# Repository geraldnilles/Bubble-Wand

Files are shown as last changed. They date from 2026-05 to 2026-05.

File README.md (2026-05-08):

# Bubble Wand

A custom-designed, 3D-printable bubble wand and storage rack, built with [OpenSCAD](https://openscad.org/) and the [BOSL2](https://github.com/BelfrySCAD/BOSL2) library.

Designed for my daughters and their friends.

---

## Wand

OpenSCAD Source: [Bubble_Wand.scad](./Bubble_Wand.scad)

The wand consists of two printed parts:

| Part | Description |
|---|---|
| **Ring** | A thick, toothed bubble loop that holds the bubble film. The serrated edges help retain more bubble solution for bigger, stronger bubbles. |
| **Handle** | A long, slim rod that fits small hands comfortably. |

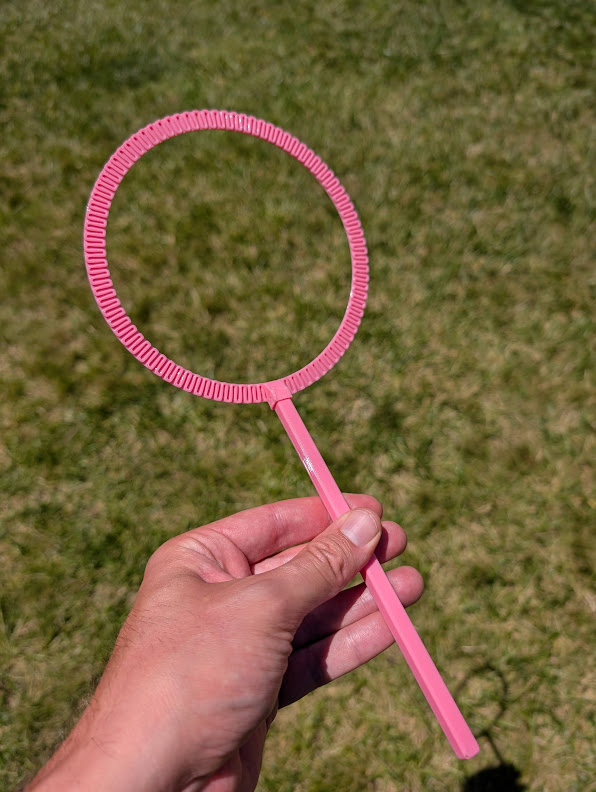
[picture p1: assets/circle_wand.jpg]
Printed bubble wand being held


Both parts are printed separately and glued together with superglue (CA glue). The handle adapter on the ring creates a strong mechanical bond.

### Ring Shapes

The wand supports **two ring profiles**, controlled by commenting/uncommenting the `radius()` function in `Bubble_Wand.scad`:

| Shape | Code |
|---|---|
| **Circular (default)** | `function radius(r,angle) = r;` |
| **Oval** | `function radius(r,angle) = ((0.5*sin(angle))^2+0.75)*r;` |

Simply uncomment your preferred line and comment the other, then re-render.

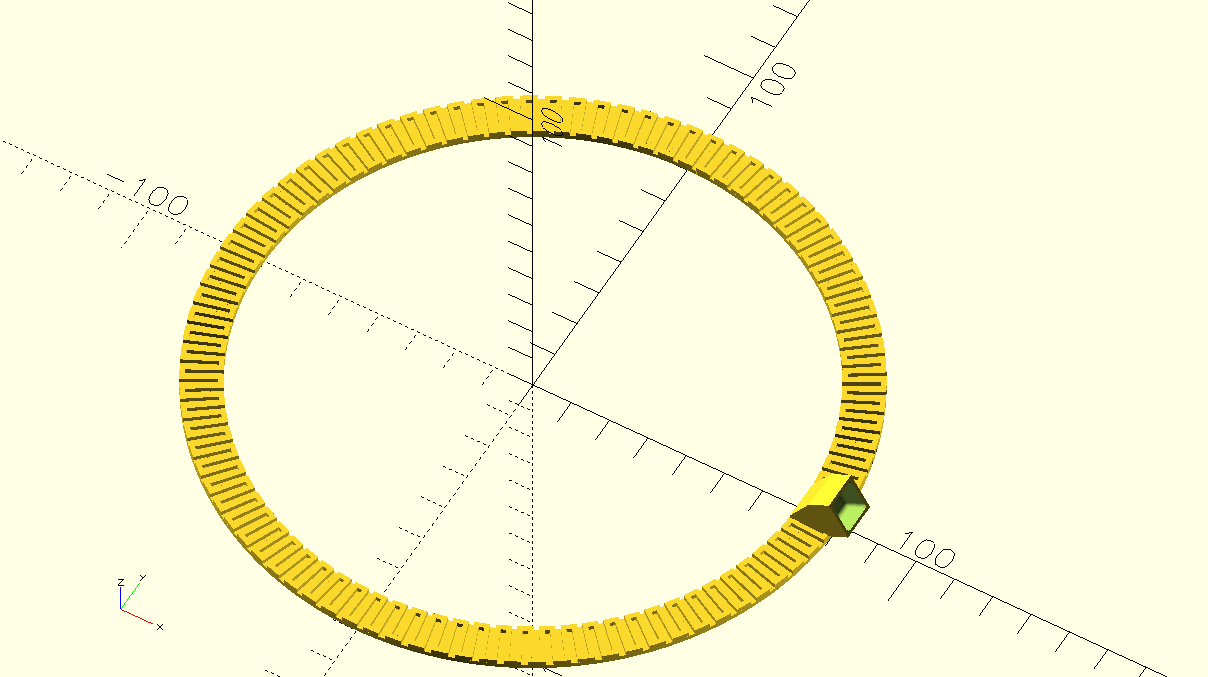
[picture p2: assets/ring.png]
Circular ring render
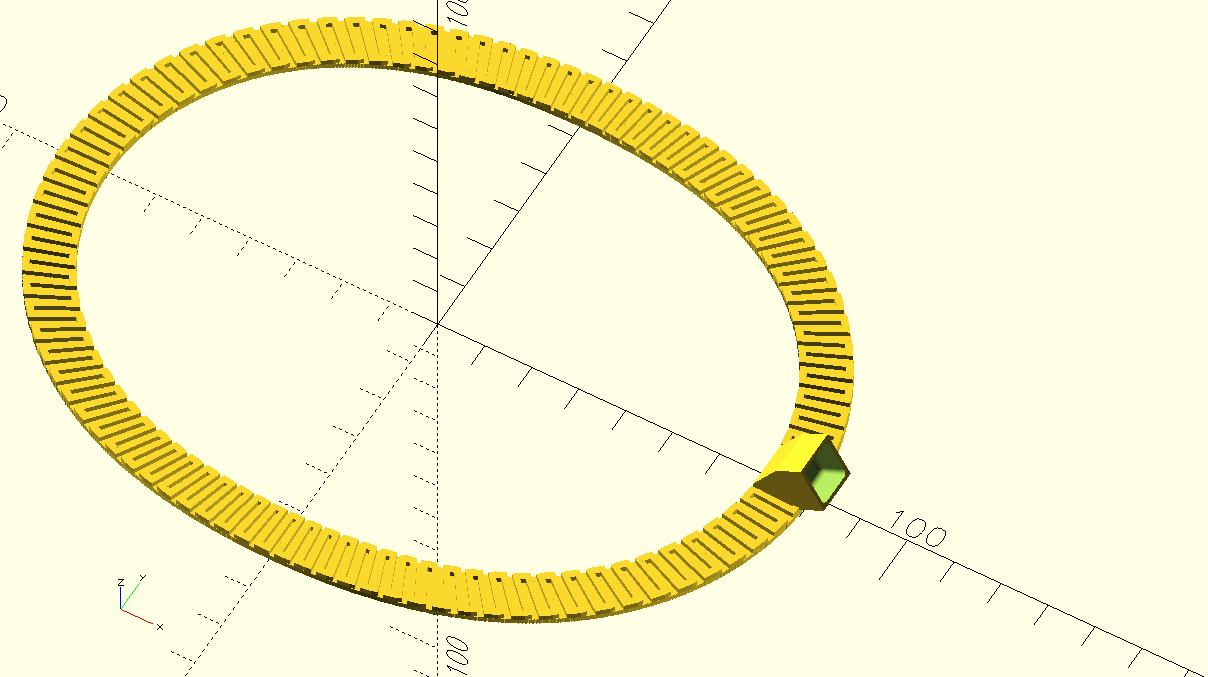
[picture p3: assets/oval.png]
Oval ring render
     

### Optimized for Clean FDM Printing

This model was designed with FDM printing in mind from the start. Every feature serves to minimize retractions, eliminate unnecessary travel moves, and produce a clean, reliable print.

- **Minimal retractions** — The zig-zag tooth pattern is laid down in a continuous, unbroken tool path. The nozzle never needs to lift or cross an open gap, so there's no oozing, stringing, or scarring on the finished part.
- **No travel moves** — Each layer of the ring consists of a single, uninterrupted extrusion. The print head moves from tooth to tooth without retracting or traveling, which saves time and reduces surface blemishes.
- **Optimized for 0.6mm nozzles** — The 1.2mm slot width is exactly two extrusion widths wide on a 0.6mm nozzle. This means the slicer can fill each tooth cleanly without gaps or thin-wall issues.
- **0.4mm nozzle compatibility** — For 0.4mm nozzles, simply increase the extrusion width to 0.6mm in your slicer settings, or decrease the `slot_width` parameter to 0.8mm.

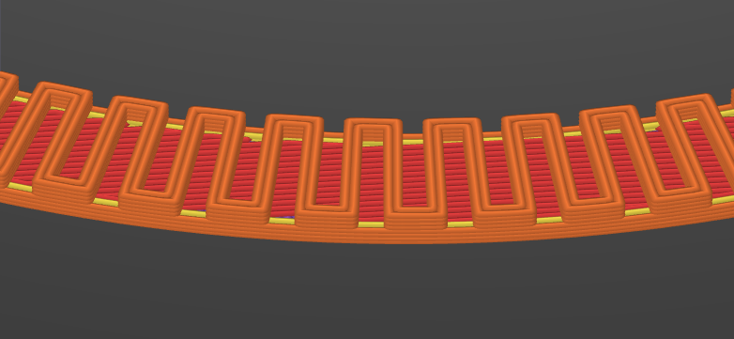
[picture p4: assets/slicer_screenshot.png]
Slicer preview showing the continuous, uninterrupted tool path across the zig-zag tooth pattern


The screenshot above shows the print path as planned by the slicer. Notice how the extruded lines flow continuously across the teeth — there are no retraction dots, no travel lines, and no visible starts or stops on the outer surface.

### Printing Instructions

**Step 1 — Render the ring with its handle adapter:**
```openscad
ring();
handle_adapter();
// handle(x=8);          // <-- keep commented
```

**Step 2 — Render the handle separately:**
```openscad
// ring();
// handle_adapter();
handle(x=8);
```

**Step 3 — Glue.** Apply superglue to the handle adapter (the small rectangular nub on the ring) and insert it into the matching hole on the handle. Hold for 30 seconds.

### Parameters

All adjustable values are at the top of `Bubble_Wand.scad`:

| Variable | Default | Description |
|---|---|---|
| `ring_radius` | `70` | Radius of the bubble ring |
| `ring_thickness` | `10` | Thickness (depth) of the ring's teeth |
| `slot_width` | `1.2` | Width of each tooth/gap |
| `slot_height` | `1.2` | Height of the tooth profile |

---

## Wand Rack / Mount

The [Wand_rack_mount.scad](./Wand_rack_mount.scad) file generates a clamp-on bracket that mounts to the edge of a surface (e.g., a bubble table, plastic stool, or bench). It can securely mount several wands.

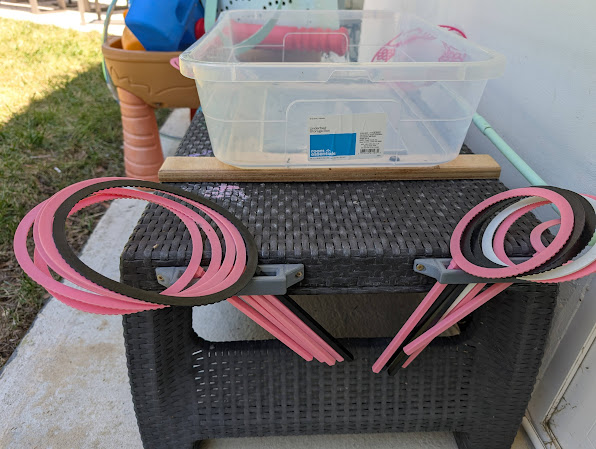
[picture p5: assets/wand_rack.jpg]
Wand rack in use


---

## Bubble Solution

See the [Bubble Solution Recipe](./Bubble_Solution.md) for the homemade bubble mix that makes these wands really shine.

---

## License

This project is open source under the [MIT License](LICENSE). Print, modify, and share freely!

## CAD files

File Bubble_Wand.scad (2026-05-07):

$fn = 50;
slot_width = 1.2;
slot_height = 1.2;
ring_thickness = 10;
ring_depth = slot_width;
step_angle = 4;

ring_radius = 70;

/***************************/
/* Oval Wand               */
/***************************/
//function radius(r,angle) = ((0.5*sin(angle))^2+0.75)*r;

/***************************/
/* Cicular Wand            */
/***************************/
function radius(r,angle) = r;

/***************************/

module tick(angle,offset){
    rotate([0,0,angle])
        translate([0,radius(ring_radius,angle),0]){
            hull(){
                cube(slot_width);
                translate([0,ring_thickness-slot_width,0])
                    cube(slot_width);
            }
        }
    hull(){
        rotate([0,0,angle])
            translate([0,radius(ring_radius,angle)
                    +ring_thickness*offset
                    -slot_width*offset,0]){
                cube(slot_width);
                
            }
        rotate([0,0,angle+step_angle/2])
            translate([0,radius(ring_radius,angle+step_angle/2)
                    +ring_thickness*offset
                    -slot_width*offset,0]){
                cube(slot_width);
                
            }
    }
}

module ring_base(){
    for (angle=[0:0.5:360])
        rotate([0,0,angle])
            translate([0,radius(ring_radius,angle),0])
                cube([slot_width,ring_thickness,slot_height]);
        

}

module ring(){
    ring_base();
    translate([0,0,ring_depth])
        for (angle=[0:step_angle:360]){
            tick(angle,0);
            tick(angle+step_angle/2,1);
        }
}

module handle_adapter(){
    x = 10;
    z = 2;
    translate([ring_radius+ring_thickness/2,0,ring_depth+slot_height-0.2])
    translate([0,0,z/4])
        difference(){
            hull(){
                cube([x,x,z/2],center=true);
                translate([5,0,x/2])
                    rotate([0,60,0])
                        cube([x,x,z*3],center=true);
            }
            translate([5,0,x/2])
                rotate([0,-30,0])
                    handle(x=8.4);
        }
}

module handle(r = 1,x=8){
    length = 180;
    translate([length/2-r*2,0,0])
    minkowski(){
        sphere(r);
        cube([length,x-r*2,x-r*2],center=true);
    }
}


// Uncomment 
ring();
handle_adapter();


//handle(x=8);

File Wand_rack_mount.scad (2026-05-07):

include <BOSL2/std.scad>

// --- Parameters ---
// Main Body Dimensions
body_w = 120;
body_d = 30;
body_h = 15;

// Slot Dimensions
slot_w = 100;
slot_d = 10;
funnel_w = 3; // NEW: How much wider the top opening is
funnel_h = 3; // NEW: How deep the funnel goes into the slot

// Flange Dimensions
flange_w = 20;    
flange_th = 5;    
gusset_drop = 15; 

// Screw Hole Dimensions
screw_d = 4.5;    
head_d = 8.5;     
head_h = 2.5;     
screw_margin = 6; 

// --- Model ---
difference() {
    union() {
        // 1. Main Body
        cuboid([body_w, body_d, body_h], rounding=2);
        
        // 2. Reinforced Mounting Flanges (Left and Right)
        for (dir = [-1, 1]) {
            hull() {
                // Outer boss
                translate([dir * (body_w/2 + flange_w - screw_margin), body_d/2 - flange_th/2, 0])
                    cuboid([screw_margin * 2, flange_th, body_h], rounding=2);
                
                // Inner base
                translate([dir * (body_w/2 - 1), body_d/2 - (flange_th + gusset_drop)/2, 0])
                    cuboid([4, flange_th + gusset_drop, body_h], rounding=2); 
            }
        }
    }
    
    // 3. Inner Slot & Funnel
    // Main vertical slot through the body
    cuboid([slot_w, slot_d, body_h + 2], rounding=1);
    
    // Top Funnel Chamfer
    // Shifted slightly above the surface (+0.01) to prevent rendering artifacts
    up(body_h/2 + 0.01)
        prismoid(
            size1 = [slot_w, slot_d], 
            size2 = [slot_w + funnel_w*2, slot_d + funnel_w*2], 
            h = funnel_h, 
            rounding = 1, // Matches the rounding of the main slot
            anchor = TOP  // Ensures the wide part stays locked to the top surface
        );
    
    // 4. Countersunk Screw Holes
    for (dir = [-1, 1]) {
        translate([dir * (body_w/2 + flange_w - screw_margin), body_d/2 - flange_th/2, 0])
            xrot(90) { 
                
                // Main through-hole 
                cyl(d=screw_d, l=50);
                
                // Countersink
                up(flange_th/2 + 0.01) 
                    cyl(d1=screw_d, d2=head_d, l=head_h, anchor=TOP);
                
                // Clearance shaft 
                up(flange_th/2)
                    cyl(d=head_d, l=20, anchor=BOTTOM);
            }
    }
}

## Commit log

2026-05-07 Frist commit
    [Bubble_Wand.scad, Wand_rack_mount.scad]
2026-05-07 Add submodule
    [Wand_rack_mount.scad]
2026-05-08 Add note about 3D printer settings
